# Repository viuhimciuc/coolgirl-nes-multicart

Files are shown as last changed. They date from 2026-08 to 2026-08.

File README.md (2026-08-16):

# 🎮 COOLGIRL - Ultimate Multigame Cartridge for Nintendo Entertainment System

The goal of this project is to create a Nintendo Entertainment System (NES) cartridge in KiCad based on the [coolgirl-famicom-multicart](https://github.com/ClusterM/coolgirl-famicom-multicart) project. This hardware design remains functionally identical to ClusterM's original project and can support up to ~700 games across various mappers.

### 🛠️ Architecture Overview
* **🧠 CPLD Core**: Uses the EPM1270T144 chip to emulate various mappers.
* **💾 Memory Layout**: PRG and CHR data share a single flash memory chip.
* **⚡ Boot Sequence**: The bootloader copies CHR data from Flash to CHR-RAM before game launch.
* **⚙️ Configuration**: Registers manage PRG offsets, bank modes, and mapper IDs.
* **🔒 Security**: Features a dedicated write-protection lock bit to secure settings after configuration.

## 📋 Full Characteristics
* **PRG ROM**: Up to 128 MiB
* **CHR RAM**: Up to 512 KiB
* **PRG RAM**: 32 KiB, non-volatile (FRAM) (optional)

---

## 🚀 How to Build

### 🔌 Hardware

#### 📄 Bill of Materials
* 🛒 [BoM](Coolgirl-NES_Rev6.x/production/bom.csv)

#### 🗺️ Schematic
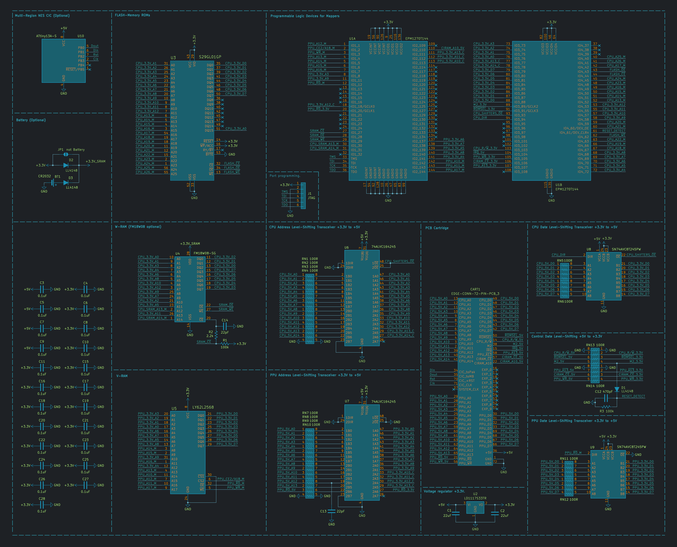
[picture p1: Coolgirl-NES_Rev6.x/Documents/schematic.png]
Schematic

* The [kicad_sch](Coolgirl-NES_Rev6.x/Coolgirl-NES_Rev6.x.kicad_sch) file can be opened using [KiCad](https://kicad.org).
 
#### 🎛️ PCB Design
The board is designed for ordering on [jlcpcb.com](https://jlcpcb.com).

| 🟢 3D Render (Top) | 🔵 3D Render (Bottom) |
| :---: | :---: |
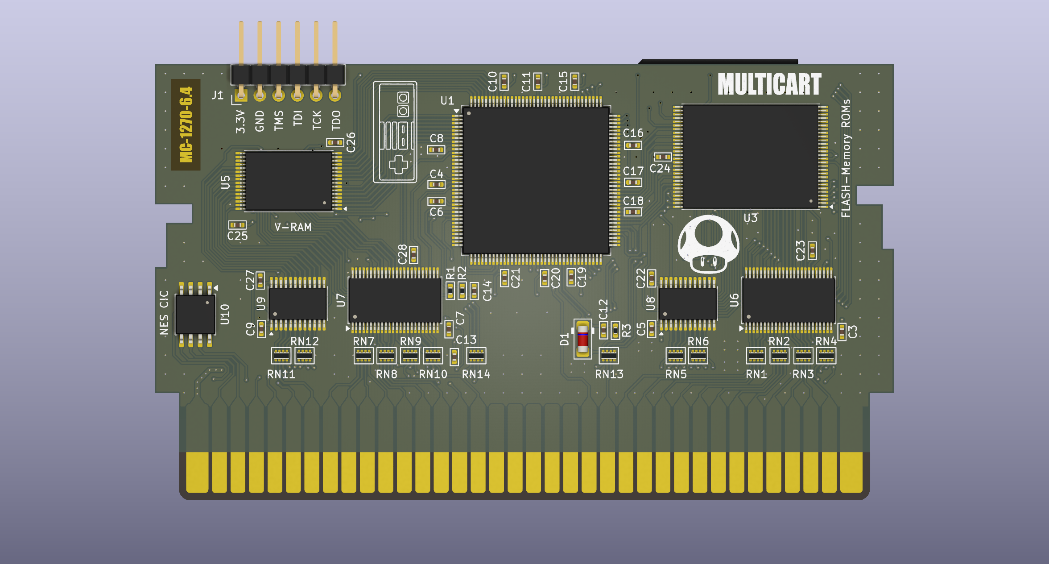
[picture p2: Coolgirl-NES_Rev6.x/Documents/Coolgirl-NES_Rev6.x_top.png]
PCB Top
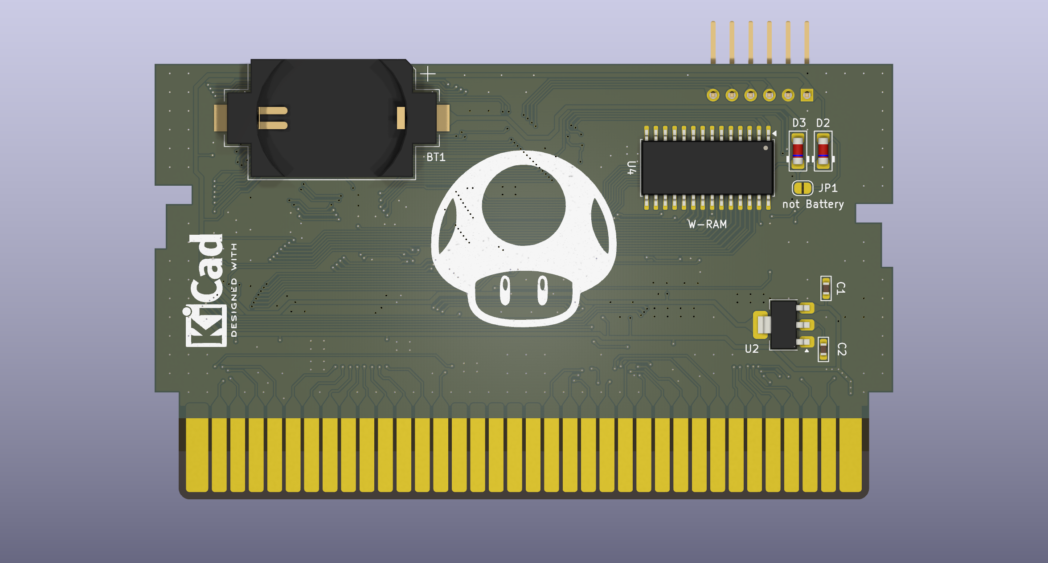
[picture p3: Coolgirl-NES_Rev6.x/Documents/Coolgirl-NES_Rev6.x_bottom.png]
PCB Bottom
|  |  |

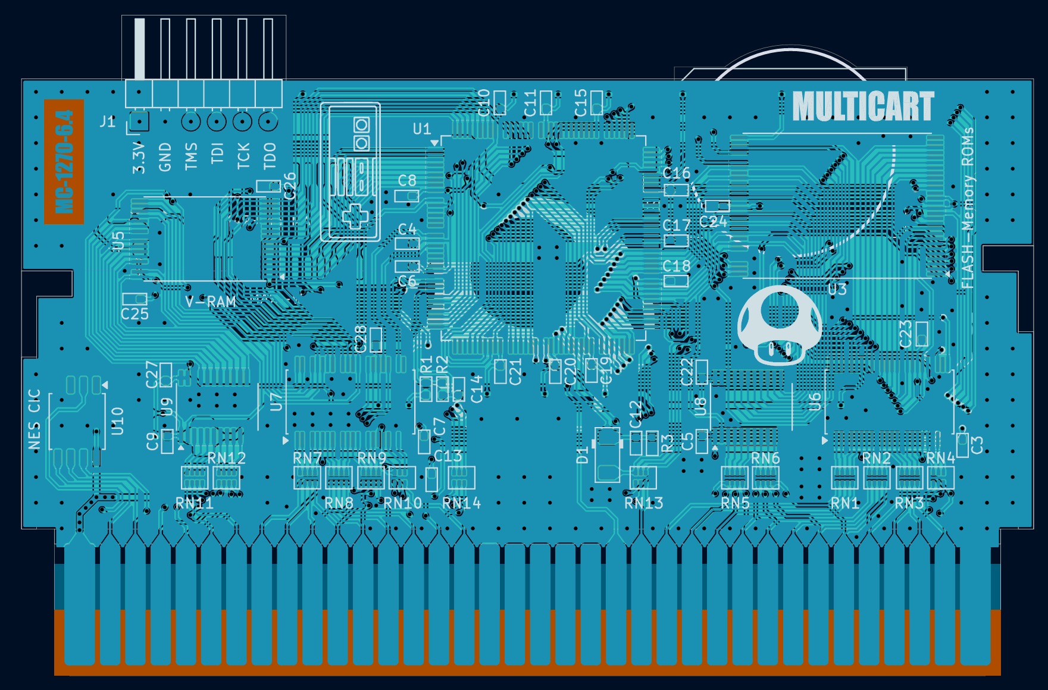
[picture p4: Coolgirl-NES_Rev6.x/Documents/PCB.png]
PCB Layout

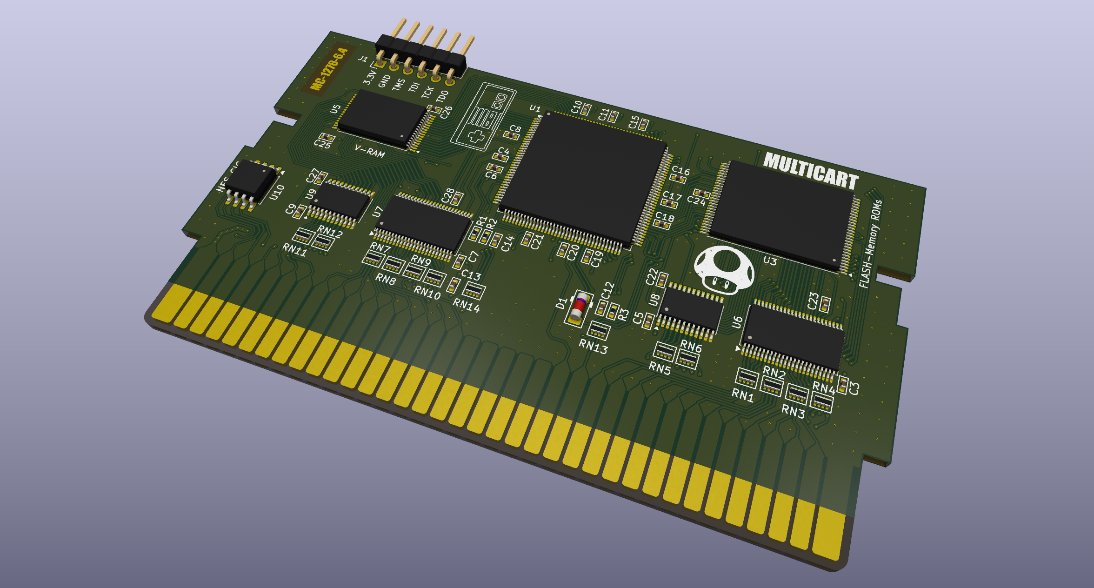
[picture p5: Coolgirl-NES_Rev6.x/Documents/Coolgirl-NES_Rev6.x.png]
Board Preview


* **Layers**: 2
* **PCB Thickness**: 1.2mm
* **Edge Connectors**: Gold fingers are highly recommended

* 📂 Layout source: [kicad_pcb](Coolgirl-NES_Rev6.x/Coolgirl-NES_Rev6.x.kicad_pcb) can be opened using [KiCad](https://kicad.org).
* 📦 Production files: Generated gerbers are located in the [Coolgirl-NES_Rev6.x/production](Coolgirl-NES_Rev6.x/production) directory.

### 💾 Firmware
All firmware and register descriptions are sourced from the [coolgirl-famicom-multicart](https://github.com/ClusterM/coolgirl-famicom-multicart/tree/master) project, corresponding to the board revision.

EPM1270T144 CPLD firmware can be compiled using the [Quartus Prime Lite 21.1](https://www.altera.com/downloads/fpga-development-tools/quartus-prime-lite-edition-design-software-version-21-1-windows). Open [CoolGirl.qpf](https://github.com/ClusterM/coolgirl-famicom-multicart/blob/master/CoolGirl_rev6.x/CoolGirl.qpf) to configure and compile project.

All mappers can't fit into the CPLD at once, so you need to select required mappers in [config file](https://github.com/ClusterM/coolgirl-famicom-multicart/blob/master/CoolGirl_config.vh), so they can fit into 1270 macrocells. Also, you can set `RESET_COMBINATION` parameter to specify software reset button combination, it works on original consoles and some famiclones. Default combination is `8'b11010010` (Left+Start+A+B). Set it to 0 to disable and free some macrocells.

There are JTAG pads on the cartridge board to connect programmer (USB Blaster).

### 💿 ROM Preparing
You can use my [COOLGIRL Multirom Builder based on ca65](https://github.com/viuhimciuc/coolgirl-multirom-builder-ca65)

Loader menu1

and also use from [COOLGIRL Multirom Builder](https://github.com/ClusterM/coolgirl-multirom-builder)

Loader menu2

to combine multiple ROMs into one with menu and loader. ROM can be written to assembled cartridge using [Famicom/NES Dumper/Writer](https://github.com/ClusterM/famicom-dumper-writer). Non-soldered flash memory chip can be written using programmer.

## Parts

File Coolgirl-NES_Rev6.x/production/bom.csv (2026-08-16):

Designator | Footprint | Quantity | Value | LCSC Part #
BT1 | BatteryHolder_Keystone_1060_1x2032 | 1 | CR2032
C1, C2 | 0603 | 2 | 22uF
C10, C11, C15, C16, C17, C18, C19, C20, C21, C22, C23, C24, C25, C26, C27, C28, C3, C4, C5, C6, C7, C8, C9 | 0402 | 23 | 0.1uF
C12 | 0402 | 1 | 470pF
C13, C14 | 0402 | 2 | 22pF
CART1 | PCB_3-CART-72-2.50-CONN | 1 | EDGE-CONN-72-PIN-PCB_3
D1, D2, D3 | D_MiniMELF | 3 | LL4148
J1 | PinHeader_1x06_P2.54mm_Horizontal | 1 | JTAG
R1, R3 | 0402 | 2 | 100k
R2 | 0402 | 1 | 2.2k
RN1, RN10, RN11, RN12, RN13, RN14, RN2, RN3, RN4, RN5, RN6, RN7, RN8, RN9 | R_Array_Concave_4x0402 | 14 | 100R
U1 | LQFP-144_20x20mm_P0.5mm | 1 | EPM1270T144
U10 | SOIC-8_5.3x5.3mm_P1.27mm | 1 | ATtiny13A-S
U2 | SOT-223-3_TabPin2 | 1 | LD1117S33TR
U3 | TSOP-I-56_18.4x14mm_P0.5mm | 1 | S29GL01GP
U4 | SOIC-28W_7.5x17.9mm_P1.27mm | 1 | FM18W08-SG
U5 | TSOP-I-32_11.8x8mm_P0.5mm | 1 | LY62L2568
U6, U7 | TSSOP-48_6.1x12.5mm_P0.5mm | 2 | 74ALVC164245
U8, U9 | TSSOP-24_4.4x7.8mm_P0.65mm | 2 | SN74AVC8T245PW

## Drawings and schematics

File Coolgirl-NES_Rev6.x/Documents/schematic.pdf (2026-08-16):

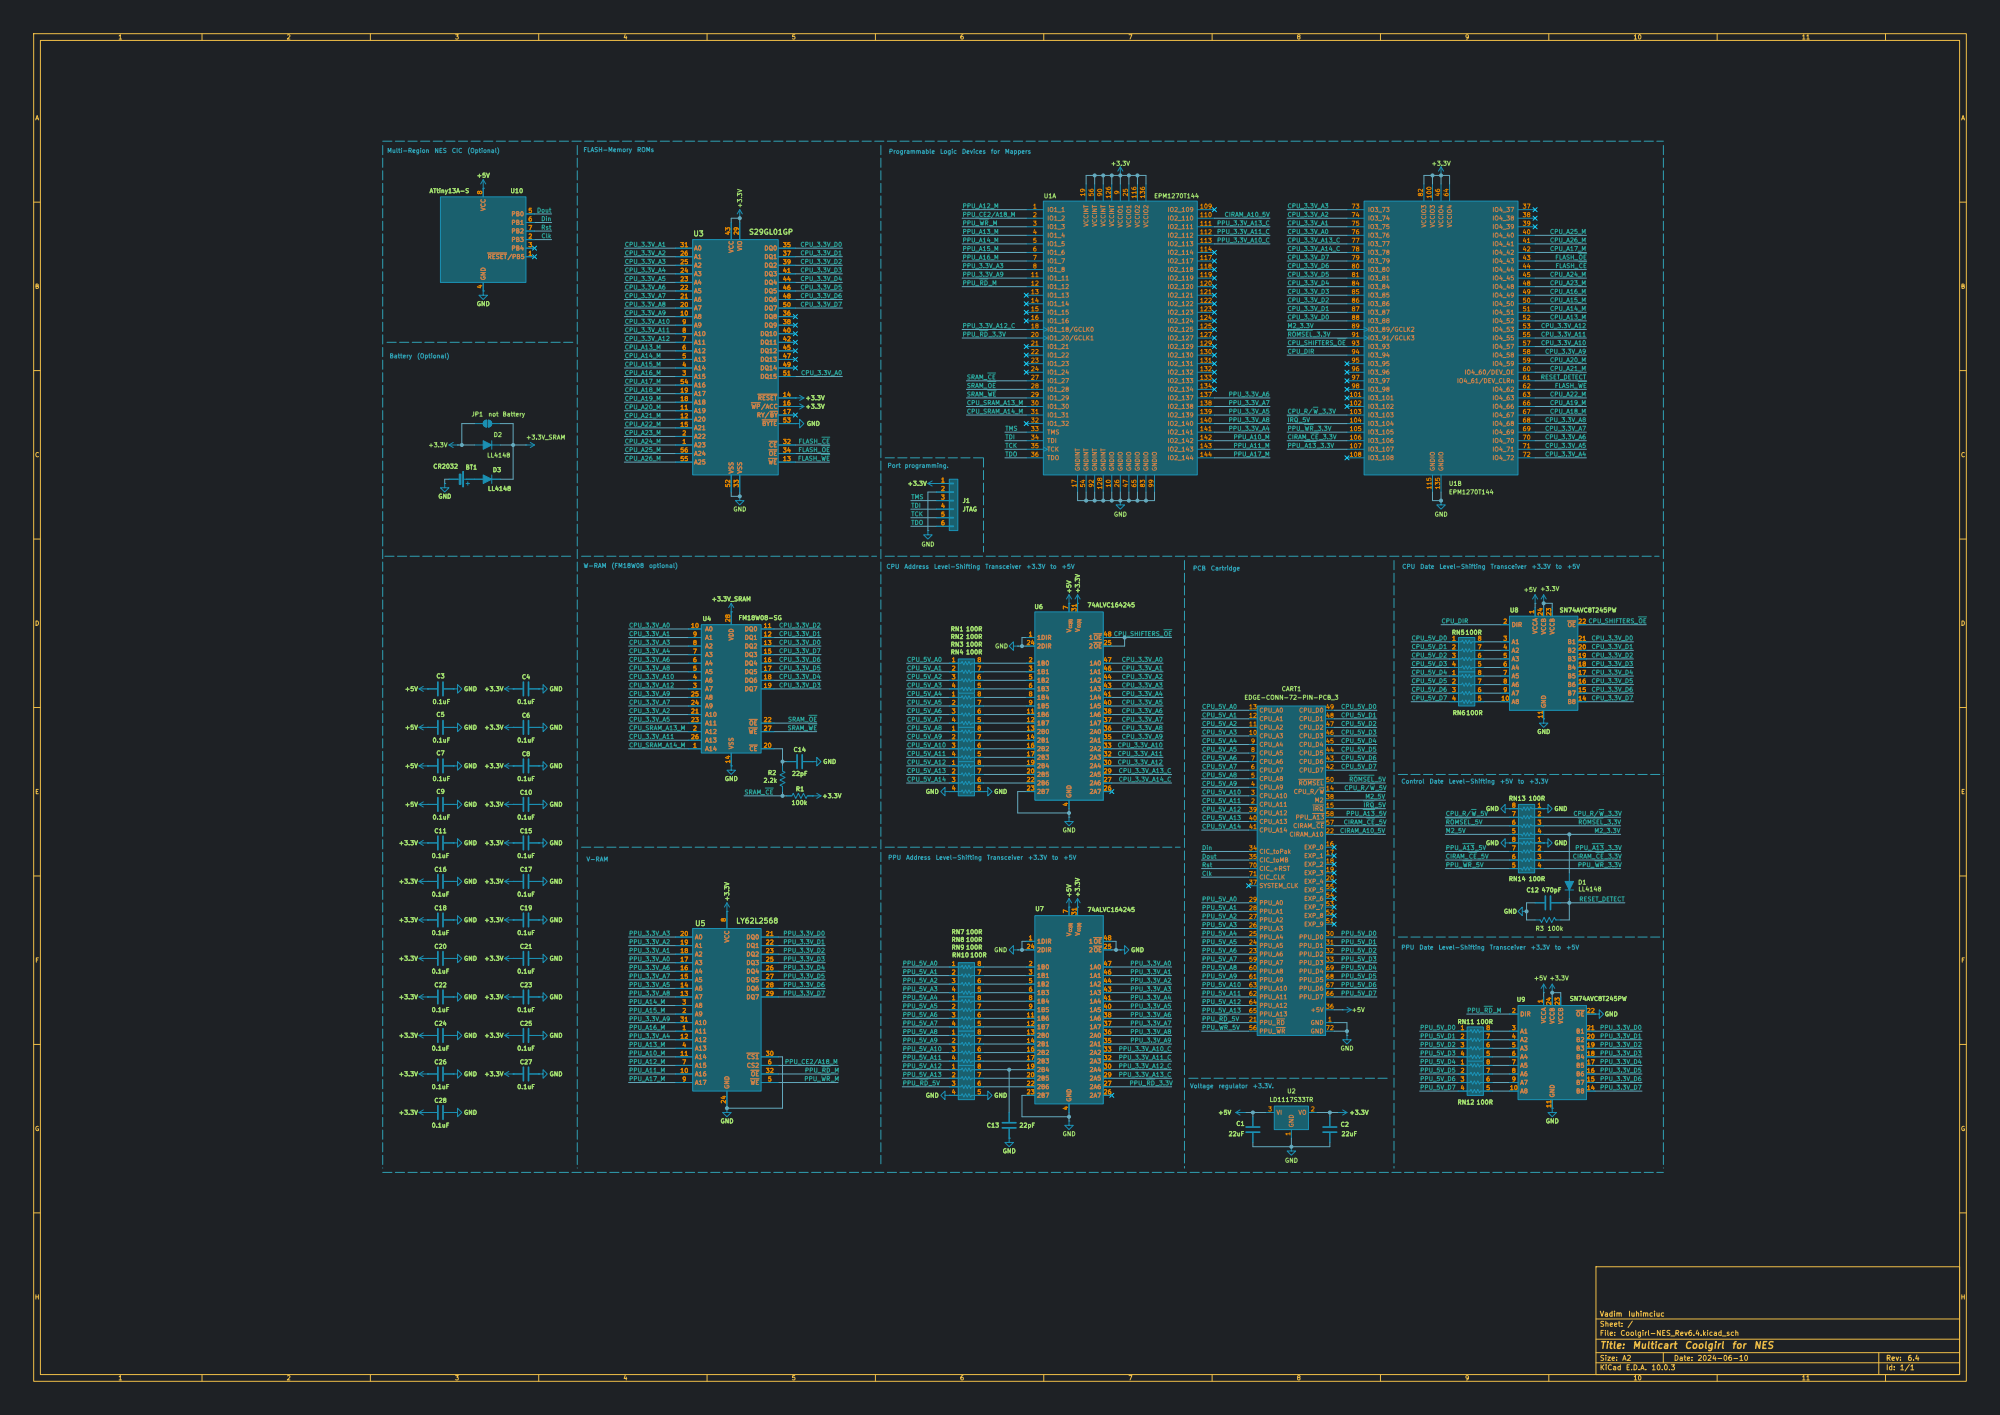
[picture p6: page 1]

Multi-Region NES CIC (Optional)

21 OE 22 VCCB 23 VCCB 24 GND

2B5 20
2B6 22
2B7 23

Sheet: /
File: Coolgirl-NES_Rev6.4.kicad_sch
Title: Multicart Coolgirl for NES

Size: A2 | Rev: 6.4
KiCad E.D.A. 10.0.3 | Id: 1/1

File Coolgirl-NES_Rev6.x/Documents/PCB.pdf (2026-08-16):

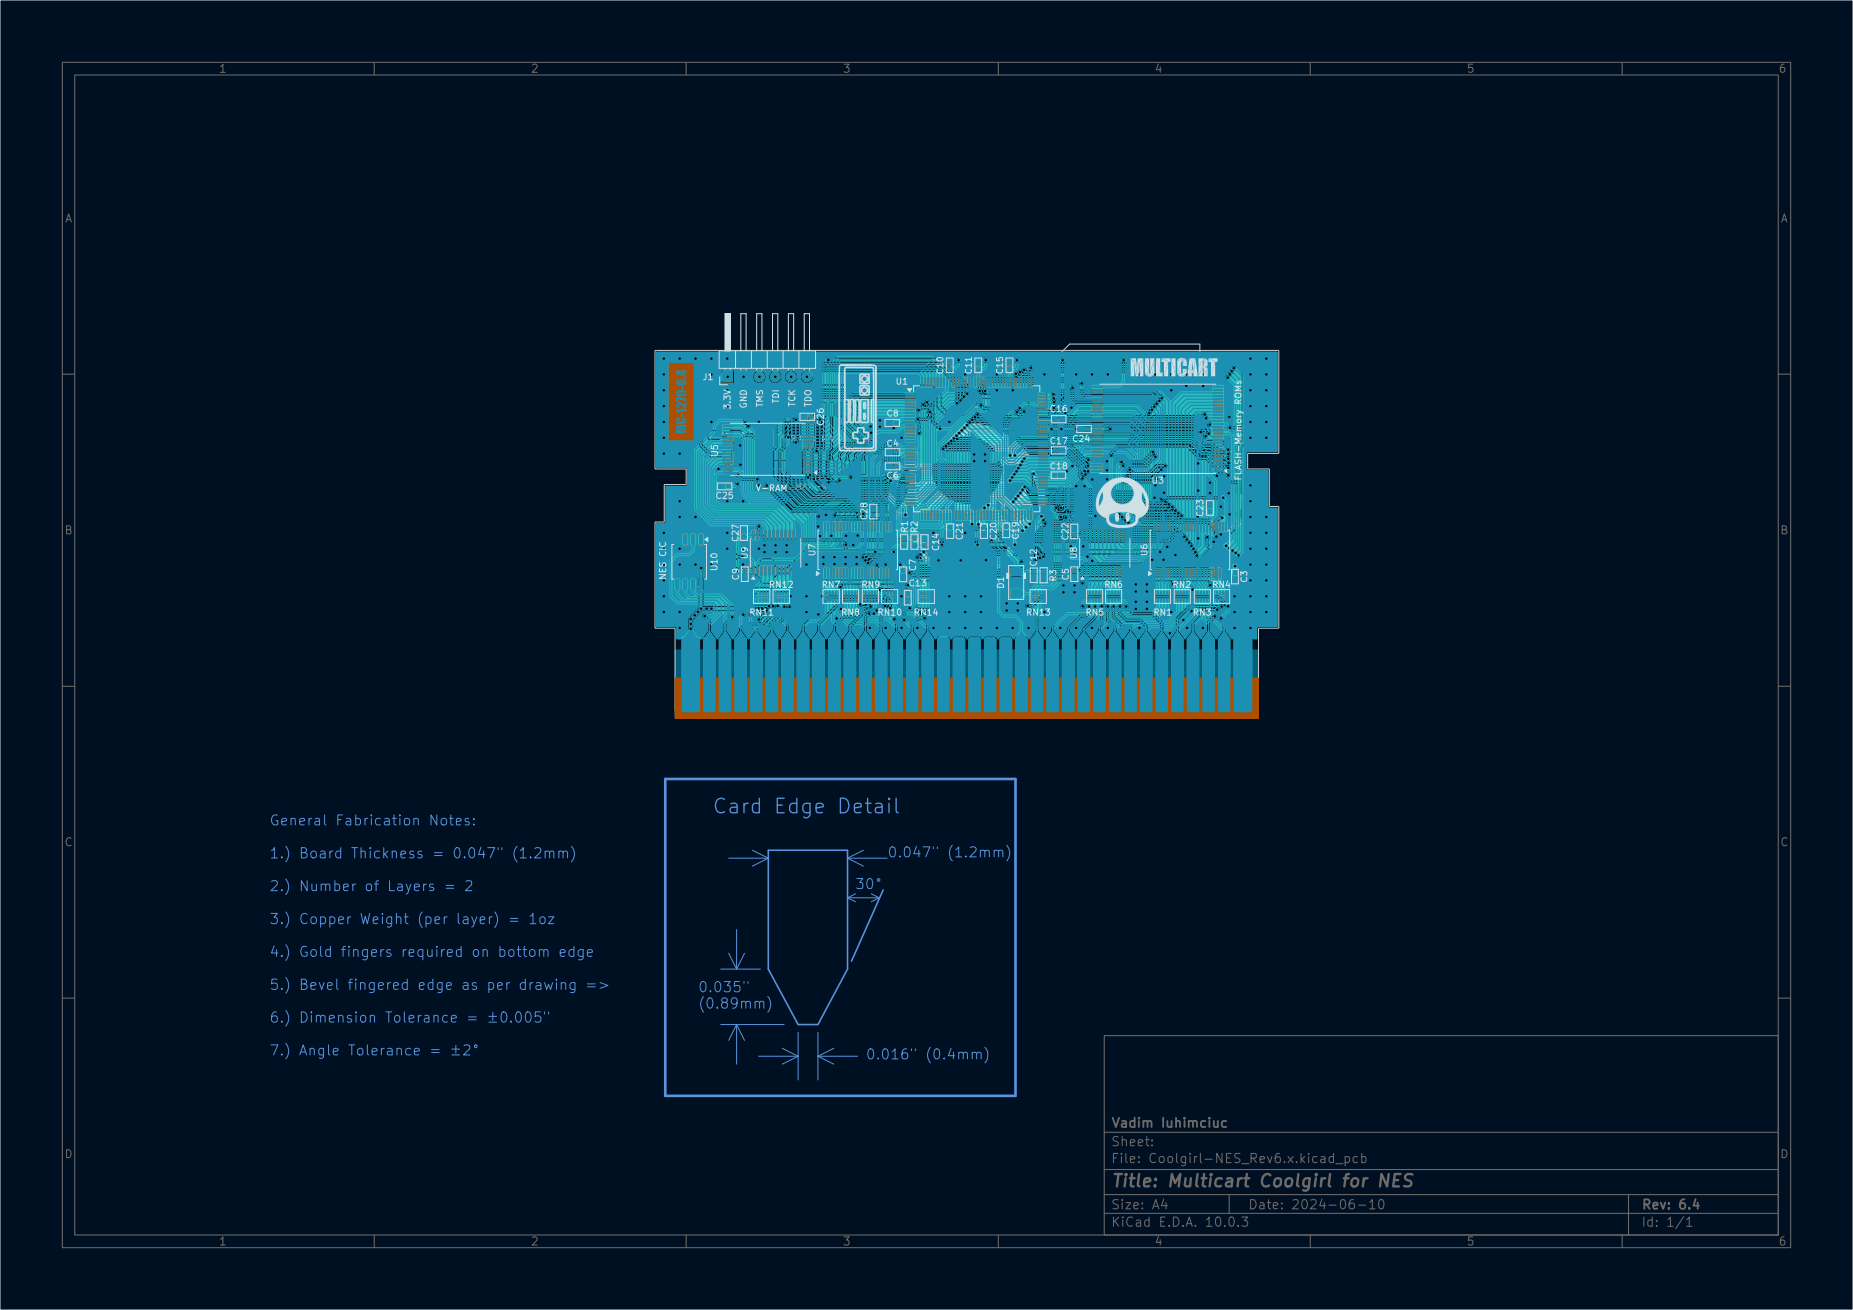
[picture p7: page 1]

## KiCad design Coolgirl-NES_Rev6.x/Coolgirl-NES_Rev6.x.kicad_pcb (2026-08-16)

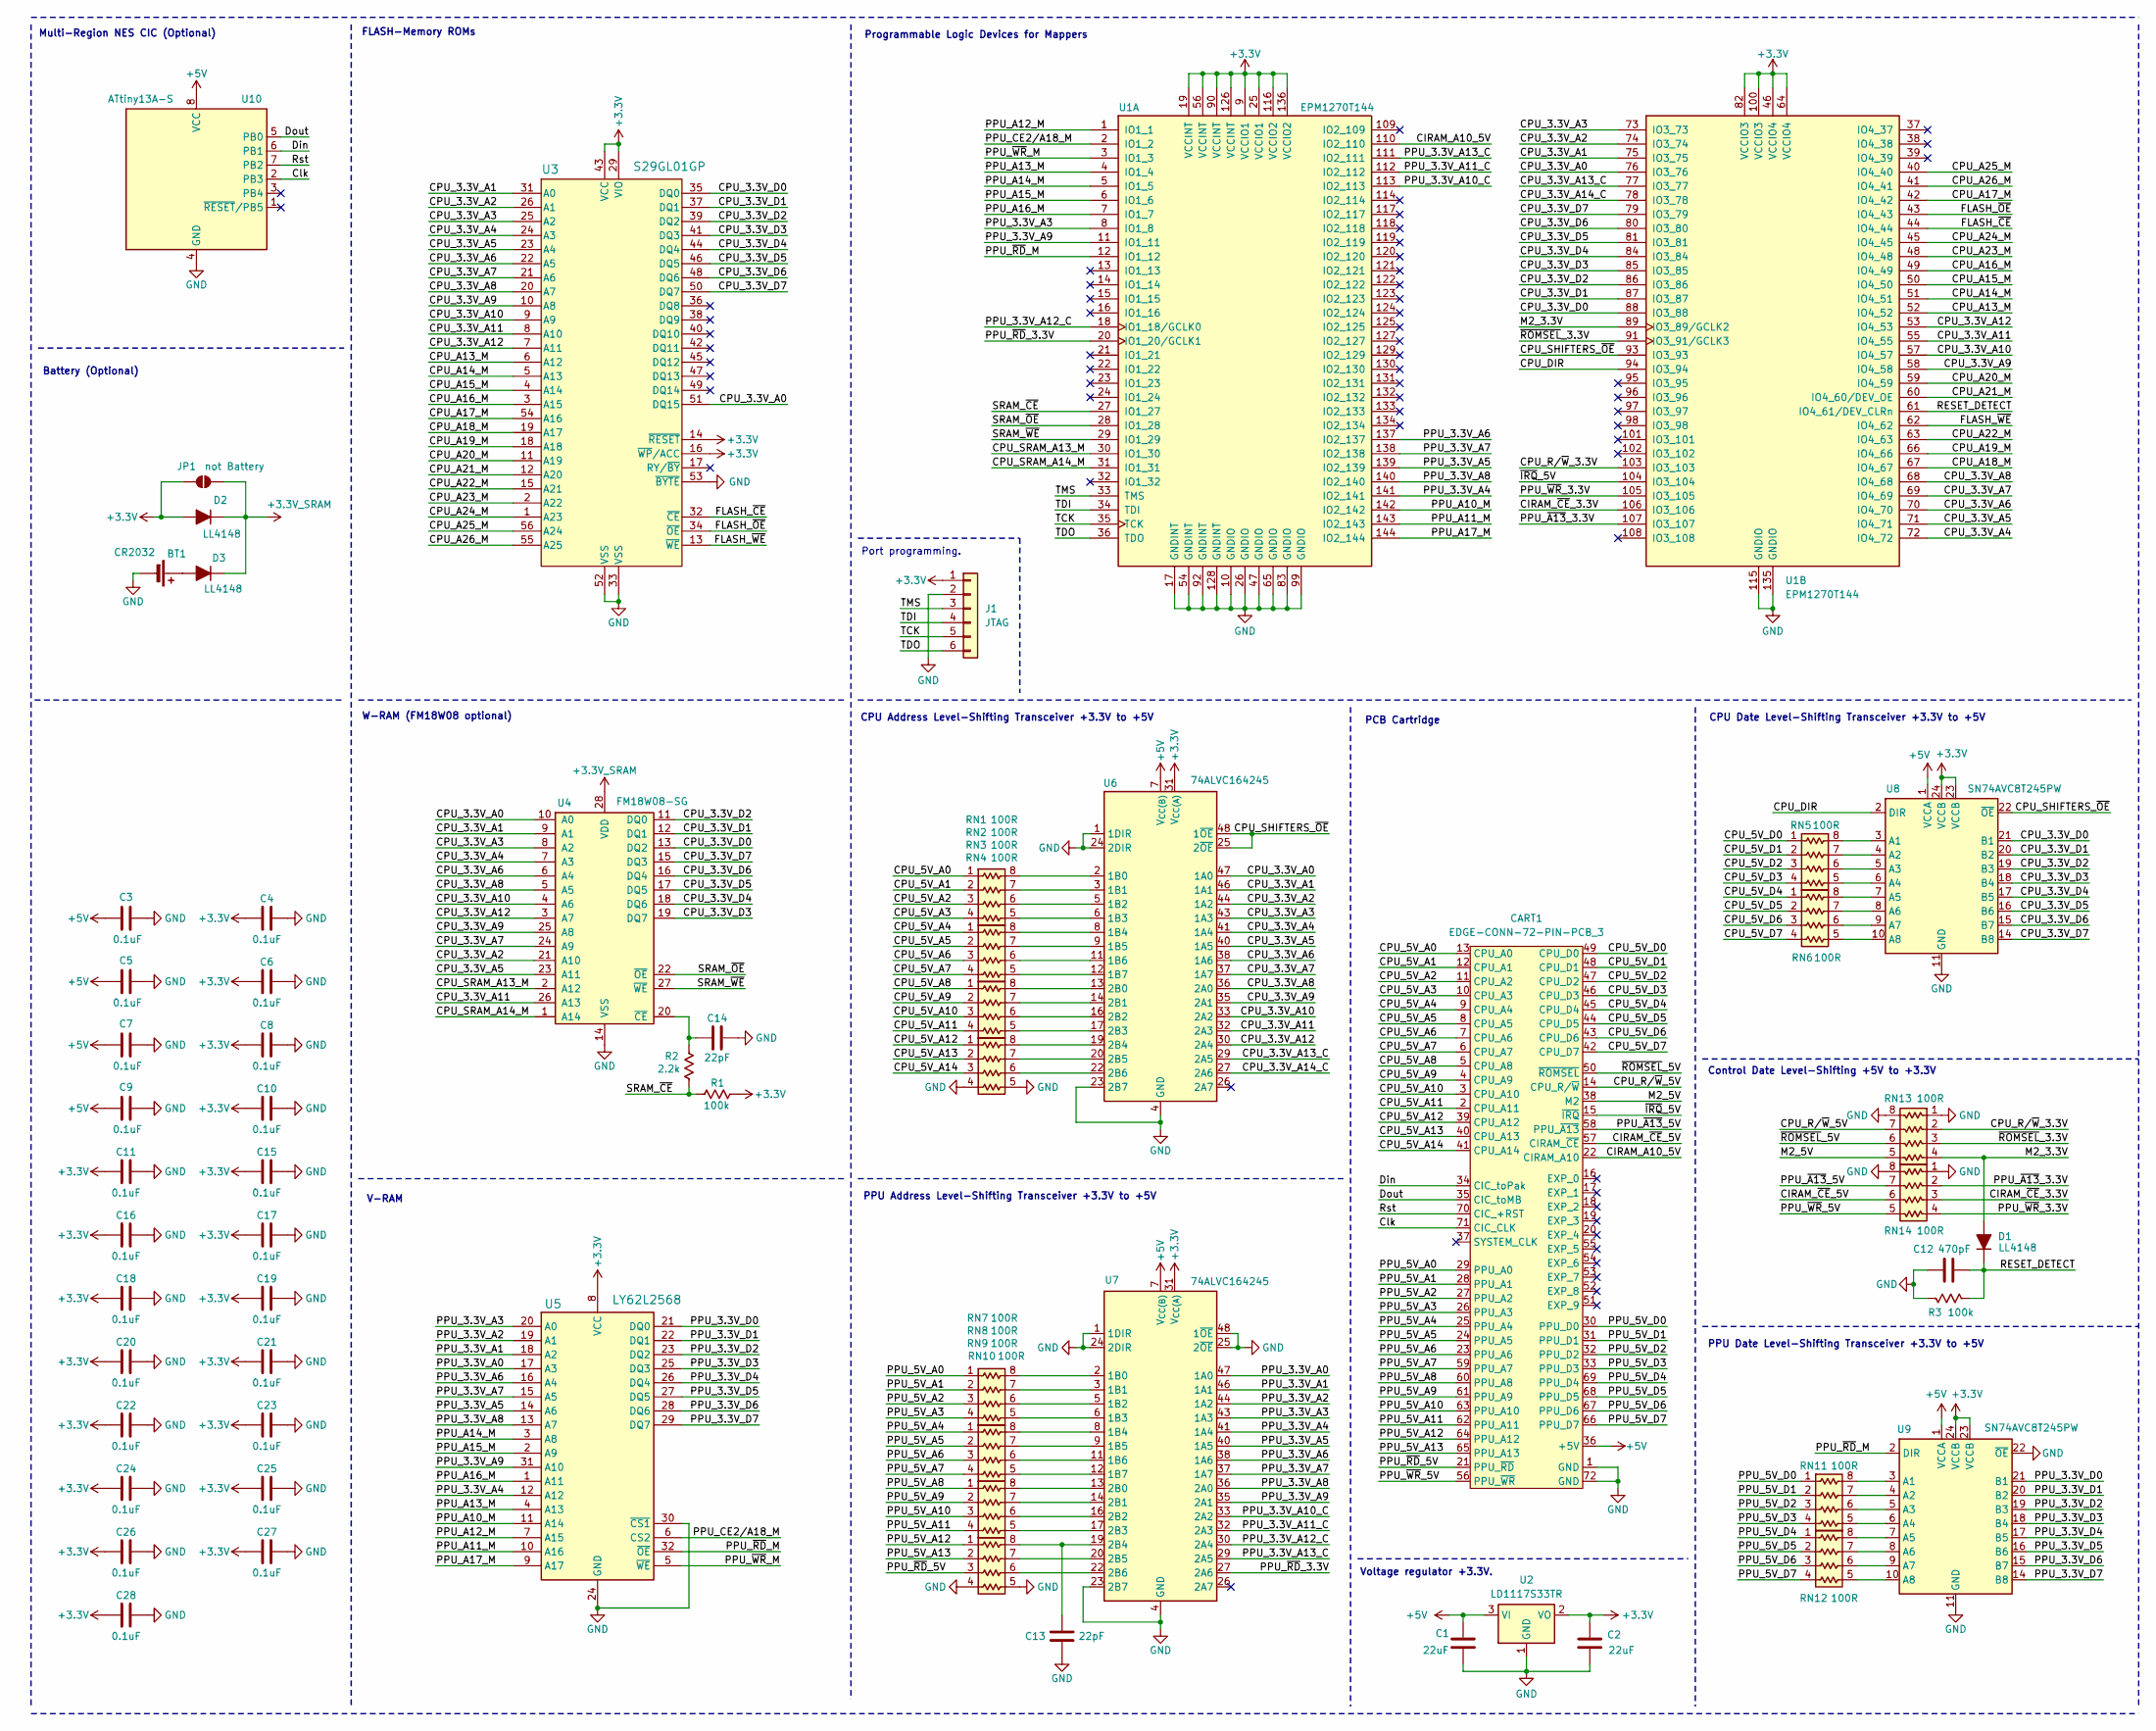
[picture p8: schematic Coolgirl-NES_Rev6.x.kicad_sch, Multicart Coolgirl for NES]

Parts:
BT1: CR2032; BatteryHolder_Keystone_1060_1x2032
C1, C2: 22uF; C_0603_1608Metric_Pad1.08x0.95mm_HandSolder
C3, C4, C5, C6, C7, C8, C9, C10, C11, C15, C16, C17, C18, C19, C20, C21, C22, C23, C24, C25, C26, C27, C28: 0.1uF; C_0402_1005Metric_Pad0.74x0.62mm_HandSolder
C12: 470pF; C_0402_1005Metric_Pad0.74x0.62mm_HandSolder
C13, C14: 22pF; C_0402_1005Metric_Pad0.74x0.62mm_HandSolder
CART1: EDGE-CONN-72-PIN-PCB_3; PCB_3-CART-72-2.50-CONN
D1, D2, D3: LL4148; D_MiniMELF
J1: JTAG; PinHeader_1x06_P2.54mm_Horizontal
JP1: not Battery; SolderJumper-2_P1.3mm_Open_RoundedPad1.0x1.5mm
R1, R3: 100k; R_0402_1005Metric_Pad0.72x0.64mm_HandSolder
R2: 2.2k; R_0402_1005Metric_Pad0.72x0.64mm_HandSolder
RN1, RN2, RN3, RN4, RN5, RN6, RN7, RN8, RN9, RN10, RN11, RN12, RN13, RN14: 100R; R_Array_Concave_4x0402
U1: EPM1270T144; LQFP-144_20x20mm_P0.5mm
U2: LD1117S33TR; SOT-223-3_TabPin2
U3: S29GL01GP; TSOP-I-56_18.4x14mm_P0.5mm
U4: FM18W08-SG; SOIC-28W_7.5x17.9mm_P1.27mm
U5: LY62L2568; TSOP-I-32_11.8x8mm_P0.5mm
U6, U7: 74ALVC164245; TSSOP-48_6.1x12.5mm_P0.5mm
U8, U9: SN74AVC8T245PW; TSSOP-24_4.4x7.8mm_P0.65mm
U10: ATtiny13A-S; SOIC-8_5.3x5.3mm_P1.27mm

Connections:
+3.3V: C2.1, C4.1, C6.1, C8.1, C10.1, C11.1, C15.1, C16.1, C17.1, C18.1, C19.1, C20.1, C21.1, C22.1, C23.1, C24.1, C25.1, C26.1, C27.1, C28.1, D2.2 (A), J1.1, JP1.1 (A), R1.1, U1.9 (VCCIO1), U1.19 (VCCINT), U1.25 (VCCIO1), U1.46 (VCCIO4), U1.56 (VCCINT), U1.64 (VCCIO4), U1.82 (VCCIO3), U1.90 (VCCINT), U1.100 (VCCIO3), U1.116 (VCCIO2), U1.126 (VCCINT), U1.136 (VCCIO2), U2.2 (VO), U3.14 (~RESET), U3.16 (~WP/ACC), U3.29 (VIO), U3.43 (VCC), U5.8 (VCC), U6.31 (V_{CC(A)}), U6.42 (V_{CC(A)}), U7.31 (V_{CC(A)}), U7.42 (V_{CC(A)}), U8.23 (VCCB), U8.24 (VCCB), U9.23 (VCCB), U9.24 (VCCB)
+3.3V_SRAM: D2.1 (K), D3.1 (K), JP1.2 (B), U4.28 (VDD)
+5V: C1.1, C3.1, C5.1, C7.1, C9.1, CART1.36 (+5V), U2.3 (VI), U6.7 (V_{CC(B)}), U6.18 (V_{CC(B)}), U7.7 (V_{CC(B)}), U7.18 (V_{CC(B)}), U8.1 (VCCA), U9.1 (VCCA), U10.8 (VCC)
/CIRAM_A10_5V: CART1.22 (CIRAM_A10), U1.110 (IO2_110)
/CIRAM_~CE_3.3V: RN14.3 (R3.1), U1.106 (IO3_106)
/CIRAM_~CE_5V: CART1.57 (CIRAM_~CE), RN14.6 (R3.2)
/CPU_3.3V_A0: U1.76 (IO3_76), U3.51 (DQ15), U4.10 (A0), U6.47 (1A0)
/CPU_3.3V_A1: U1.75 (IO3_75), U3.31 (A0), U4.9 (A1), U6.46 (1A1)
/CPU_3.3V_A2: U1.74 (IO3_74), U3.26 (A1), U4.21 (A10), U6.44 (1A2)
/CPU_3.3V_A3: U1.73 (IO3_73), U3.25 (A2), U4.8 (A2), U6.43 (1A3)
/CPU_3.3V_A4: U1.72 (IO4_72), U3.24 (A3), U4.7 (A3), U6.41 (1A4)
/CPU_3.3V_A5: U1.71 (IO4_71), U3.23 (A4), U4.23 (A11), U6.40 (1A5)
/CPU_3.3V_A6: U1.70 (IO4_70), U3.22 (A5), U4.6 (A4), U6.38 (1A6)
/CPU_3.3V_A7: U1.69 (IO4_69), U3.21 (A6), U4.24 (A9), U6.37 (1A7)
/CPU_3.3V_A8: U1.68 (IO4_68), U3.20 (A7), U4.5 (A5), U6.36 (2A0)
/CPU_3.3V_A9: U1.58 (IO4_58), U3.10 (A8), U4.25 (A8), U6.35 (2A1)
/CPU_3.3V_A10: U1.57 (IO4_57), U3.9 (A9), U4.4 (A6), U6.33 (2A2)
/CPU_3.3V_A11: U1.55 (IO4_55), U3.8 (A10), U4.26 (A13), U6.32 (2A3)
/CPU_3.3V_A12: U1.53 (IO4_53), U3.7 (A11), U4.3 (A7), U6.30 (2A4)
/CPU_3.3V_A13_C: U1.77 (IO3_77), U6.29 (2A5)
/CPU_3.3V_A14_C: U1.78 (IO3_78), U6.27 (2A6)
/CPU_3.3V_D0: U1.88 (IO3_88), U3.35 (DQ0), U4.13 (DQ2), U8.21 (B1)
/CPU_3.3V_D1: U1.87 (IO3_87), U3.37 (DQ1), U4.12 (DQ1), U8.20 (B2)
/CPU_3.3V_D2: U1.86 (IO3_86), U3.39 (DQ2), U4.11 (DQ0), U8.19 (B3)
/CPU_3.3V_D3: U1.85 (IO3_85), U3.41 (DQ3), U4.19 (DQ7), U8.18 (B4)
/CPU_3.3V_D4: U1.84 (IO3_84), U3.44 (DQ4), U4.18 (DQ6), U8.17 (B5)
/CPU_3.3V_D5: U1.81 (IO3_81), U3.46 (DQ5), U4.17 (DQ5), U8.16 (B6)
/CPU_3.3V_D6: U1.80 (IO3_80), U3.48 (DQ6), U4.16 (DQ4), U8.15 (B7)
/CPU_3.3V_D7: U1.79 (IO3_79), U3.50 (DQ7), U4.15 (DQ3), U8.14 (B8)
/CPU_5V_A0: CART1.13 (CPU_A0), RN1.1 (R1.1)
/CPU_5V_A1: CART1.12 (CPU_A1), RN1.2 (R2.1)
/CPU_5V_A2: CART1.11 (CPU_A2), RN1.3 (R3.1)
/CPU_5V_A3: CART1.10 (CPU_A3), RN1.4 (R4.1)
/CPU_5V_A4: CART1.9 (CPU_A4), RN2.1 (R1.1)
/CPU_5V_A5: CART1.8 (CPU_A5), RN2.2 (R2.1)
/CPU_5V_A6: CART1.7 (CPU_A6), RN2.3 (R3.1)
/CPU_5V_A7: CART1.6 (CPU_A7), RN2.4 (R4.1)
/CPU_5V_A8: CART1.5 (CPU_A8), RN3.1 (R1.1)
/CPU_5V_A9: CART1.4 (CPU_A9), RN3.2 (R2.1)
/CPU_5V_A10: CART1.3 (CPU_A10), RN3.3 (R3.1)
/CPU_5V_A11: CART1.2 (CPU_A11), RN3.4 (R4.1)
/CPU_5V_A12: CART1.39 (CPU_A12), RN4.1 (R1.1)
/CPU_5V_A13: CART1.40 (CPU_A13), RN4.2 (R2.1)
/CPU_5V_A14: CART1.41 (CPU_A14), RN4.3 (R3.1)
/CPU_5V_D0: CART1.49 (CPU_D0), RN5.1 (R1.1)
/CPU_5V_D1: CART1.48 (CPU_D1), RN5.2 (R2.1)
/CPU_5V_D2: CART1.47 (CPU_D2), RN5.3 (R3.1)
/CPU_5V_D3: CART1.46 (CPU_D3), RN5.4 (R4.1)
/CPU_5V_D4: CART1.45 (CPU_D4), RN6.1 (R1.1)
/CPU_5V_D5: CART1.44 (CPU_D5), RN6.2 (R2.1)
/CPU_5V_D6: CART1.43 (CPU_D6), RN6.3 (R3.1)
/CPU_5V_D7: CART1.42 (CPU_D7), RN6.4 (R4.1)
/CPU_A13_M: U1.52 (IO4_52), U3.6 (A12)
/CPU_A14_M: U1.51 (IO4_51), U3.5 (A13)
/CPU_A15_M: U1.50 (IO4_50), U3.4 (A14)
/CPU_A16_M: U1.49 (IO4_49), U3.3 (A15)
/CPU_A17_M: U1.42 (IO4_42), U3.54 (A16)
/CPU_A18_M: U1.67 (IO4_67), U3.19 (A17)
/CPU_A19_M: U1.66 (IO4_66), U3.18 (A18)
/CPU_A20_M: U1.59 (IO4_59), U3.11 (A19)
/CPU_A21_M: U1.60 (IO4_60/DEV_OE), U3.12 (A20)
/CPU_A22_M: U1.63 (IO4_63), U3.15 (A21)
/CPU_A23_M: U1.48 (IO4_48), U3.2 (A22)
/CPU_A24_M: U1.45 (IO4_45), U3.1 (A23)
/CPU_A25_M: U1.40 (IO4_40), U3.56 (A24)
/CPU_A26_M: U1.41 (IO4_41), U3.55 (A25)
/CPU_DIR: U1.94 (IO3_94), U8.2 (DIR)
/CPU_R/~W_3.3V: RN13.2 (R2.1), U1.103 (IO3_103)
/CPU_R/~W_5V: CART1.14 (CPU_R/~W), RN13.7 (R2.2)
/CPU_SHIFTERS_~OE: U1.93 (IO3_93), U6.25 (2~OE), U6.48 (1~OE), U8.22 (~OE)
/CPU_SRAM_A13_M: U1.30 (IO1_30), U4.2 (A12)
/CPU_SRAM_A14_M: U1.31 (IO1_31), U4.1 (A14)
/Clk: CART1.71 (CIC_CLK), U10.2 (PB3)
/Din: CART1.34 (CIC_toPak), U10.6 (PB1)
/Dout: CART1.35 (CIC_toMB), U10.5 (PB0)
/FLASH_~CE: U1.44 (IO4_44), U3.32 (~CE)
/FLASH_~OE: U1.43 (IO4_43), U3.34 (~OE)
/FLASH_~WE: U1.62 (IO4_62), U3.13 (~WE)
/M2_3.3V: D1.2 (A), RN13.4 (R4.1), U1.89 (IO3_89/GCLK2)
/M2_5V: CART1.38 (M2), RN13.5 (R4.2)
/PPU_3.3V_A0: U5.17 (A3), U7.47 (1A0)
/PPU_3.3V_A1: U5.18 (A2), U7.46 (1A1)
/PPU_3.3V_A2: U5.19 (A1), U7.44 (1A2)
/PPU_3.3V_A3: U1.8 (IO1_8), U5.20 (A0), U7.43 (1A3)
/PPU_3.3V_A4: U1.141 (IO2_141), U5.12 (A12), U7.41 (1A4)
/PPU_3.3V_A5: U1.139 (IO2_139), U5.14 (A6), U7.40 (1A5)
/PPU_3.3V_A6: U1.137 (IO2_137), U5.16 (A4), U7.38 (1A6)
/PPU_3.3V_A7: U1.138 (IO2_138), U5.15 (A5), U7.37 (1A7)
/PPU_3.3V_A8: U1.140 (IO2_140), U5.13 (A7), U7.36 (2A0)
/PPU_3.3V_A9: U1.11 (IO1_11), U5.31 (A10), U7.35 (2A1)
/PPU_3.3V_A10_C: U1.113 (IO2_113), U7.33 (2A2)
/PPU_3.3V_A11_C: U1.112 (IO2_112), U7.32 (2A3)
/PPU_3.3V_A12_C: U1.18 (IO1_18/GCLK0), U7.30 (2A4)
/PPU_3.3V_A13_C: U1.111 (IO2_111), U7.29 (2A5)
/PPU_3.3V_D0: U5.21 (DQ0), U9.21 (B1)
/PPU_3.3V_D1: U5.22 (DQ1), U9.20 (B2)
/PPU_3.3V_D2: U5.23 (DQ2), U9.19 (B3)
/PPU_3.3V_D3: U5.25 (DQ3), U9.18 (B4)
/PPU_3.3V_D4: U5.26 (DQ4), U9.17 (B5)
/PPU_3.3V_D5: U5.27 (DQ5), U9.16 (B6)
/PPU_3.3V_D6: U5.28 (DQ6), U9.15 (B7)
/PPU_3.3V_D7: U5.29 (DQ7), U9.14 (B8)
/PPU_5V_A0: CART1.29 (PPU_A0), RN7.1 (R1.1)
/PPU_5V_A1: CART1.28 (PPU_A1), RN7.2 (R2.1)
/PPU_5V_A2: CART1.27 (PPU_A2), RN7.3 (R3.1)
/PPU_5V_A3: CART1.26 (PPU_A3), RN7.4 (R4.1)
/PPU_5V_A4: CART1.25 (PPU_A4), RN8.1 (R1.1)
/PPU_5V_A5: CART1.24 (PPU_A5), RN8.2 (R2.1)
/PPU_5V_A6: CART1.23 (PPU_A6), RN8.3 (R3.1)
/PPU_5V_A7: CART1.59 (PPU_A7), RN8.4 (R4.1)
/PPU_5V_A8: CART1.60 (PPU_A8), RN9.1 (R1.1)
/PPU_5V_A9: CART1.61 (PPU_A9), RN9.2 (R2.1)
/PPU_5V_A10: CART1.63 (PPU_A10), RN9.3 (R3.1)
/PPU_5V_A11: CART1.62 (PPU_A11), RN9.4 (R4.1)
/PPU_5V_A12: CART1.64 (PPU_A12), RN10.1 (R1.1)
/PPU_5V_A13: CART1.65 (PPU_A13), RN10.2 (R2.1)
/PPU_5V_D0: CART1.30 (PPU_D0), RN11.1 (R1.1)
/PPU_5V_D1: CART1.31 (PPU_D1), RN11.2 (R2.1)
/PPU_5V_D2: CART1.32 (PPU_D2), RN11.3 (R3.1)
/PPU_5V_D3: CART1.33 (PPU_D3), RN11.4 (R4.1)
/PPU_5V_D4: CART1.69 (PPU_D4), RN12.1 (R1.1)
/PPU_5V_D5: CART1.68 (PPU_D5), RN12.2 (R2.1)
/PPU_5V_D6: CART1.67 (PPU_D6), RN12.3 (R3.1)
/PPU_5V_D7: CART1.66 (PPU_D7), RN12.4 (R4.1)
/PPU_A10_M: U1.142 (IO2_142), U5.11 (A14)
/PPU_A11_M: U1.143 (IO2_143), U5.10 (A16)
/PPU_A12_M: U1.1 (IO1_1), U5.7 (A15)
/PPU_A13_M: U1.4 (IO1_4), U5.4 (A13)
/PPU_A14_M: U1.5 (IO1_5), U5.3 (A8)
/PPU_A15_M: U1.6 (IO1_6), U5.2 (A9)
/PPU_A16_M: U1.7 (IO1_7), U5.1 (A11)
/PPU_A17_M: U1.144 (IO2_144), U5.9 (A17)
/PPU_CE2/A18_M: U1.2 (IO1_2), U5.6 (CS2)
/PPU_~A13_3.3V: RN14.2 (R2.1), U1.107 (IO3_107)
/PPU_~A13_5V: CART1.58 (PPU_~A13), RN14.7 (R2.2)
/PPU_~RD_3.3V: U1.20 (IO1_20/GCLK1), U7.27 (2A6)
/PPU_~RD_5V: CART1.21 (PPU_~RD), RN10.3 (R3.1)
/PPU_~RD_M: U1.12 (IO1_12), U5.32 (~OE), U9.2 (DIR)
/PPU_~WR_3.3V: RN14.4 (R4.1), U1.105 (IO3_105)
/PPU_~WR_5V: CART1.56 (PPU_~WR), RN14.5 (R4.2)
/PPU_~WR_M: U1.3 (IO1_3), U5.5 (~WE)
/RESET_DETECT: C12.2, D1.1 (K), R3.1, U1.61 (IO4_61/DEV_CLRn)
/Rst: CART1.70 (CIC_+RST), U10.7 (PB2)
/SRAM_~CE: R1.2, R2.1, U1.27 (IO1_27)
/SRAM_~OE: U1.28 (IO1_28), U4.22 (~OE)
/SRAM_~WE: U1.29 (IO1_29), U4.27 (~WE)
/TCK: J1.5, U1.35 (TCK)
/TDI: J1.4, U1.34 (TDI)
/TDO: J1.6, U1.36 (TDO)
/TMS: J1.3, U1.33 (TMS)
/~IRQ_5V: CART1.15 (~IRQ), U1.104 (IO3_104)
/~ROMSEL_3.3V: RN13.3 (R3.1), U1.91 (IO3_91/GCLK3)
/~ROMSEL_5V: CART1.50 (~ROMSEL), RN13.6 (R3.2)
GND: BT1.2 (-), C1.2, C2.2, C3.2, C4.2, C5.2, C6.2, C7.2, C8.2, C9.2, C10.2, C11.2, C12.1, C13.1, C14.2, C15.2, C16.2, C17.2, C18.2, C19.2, C20.2, C21.2, C22.2, C23.2, C24.2, C25.2, C26.2, C27.2, C28.2, CART1.1 (GND), CART1.72 (GND), J1.2, R3.2, RN4.4 (R4.1), RN4.5 (R4.2), RN10.4 (R4.1), RN10.5 (R4.2), RN13.1 (R1.1), RN13.8 (R1.2), RN14.1 (R1.1), RN14.8 (R1.2), U1.10 (GNDIO), U1.17 (GNDINT), U1.26 (GNDIO), U1.47 (GNDIO), U1.54 (GNDINT), U1.65 (GNDIO), U1.83 (GNDIO), U1.92 (GNDINT), U1.99 (GNDIO), U1.115 (GNDIO), U1.128 (GNDINT), U1.135 (GNDIO), U2.1 (GND), U3.33 (VSS), U3.52 (VSS), U3.53 (~BYTE), U4.14 (VSS), U5.24 (GND), U5.30 (~CS1), U6.1 (1DIR), U6.4 (GND), U6.10 (GND), U6.15 (GND), U6.21 (GND), U6.23 (2B7), U6.24 (2DIR), U6.28 (GND), U6.34 (GND), U6.39 (GND), U6.45 (GND), U7.1 (1DIR), U7.4 (GND), U7.10 (GND), U7.15 (GND), U7.21 (GND), U7.23 (2B7), U7.24 (2DIR), U7.25 (2~OE), U7.28 (GND), U7.34 (GND), U7.39 (GND), U7.45 (GND), U7.48 (1~OE), U8.11 (GND), U8.12 (GND), U8.13 (GND), U9.11 (GND), U9.12 (GND), U9.13 (GND), U9.22 (~OE), U10.4 (GND)
unnamed: BT1.1 (+), D3.2 (A)
unnamed: RN1.8 (R1.2), U6.2 (1B0)
unnamed: RN1.7 (R2.2), U6.3 (1B1)
unnamed: RN1.6 (R3.2), U6.5 (1B2)
unnamed: RN1.5 (R4.2), U6.6 (1B3)
unnamed: RN2.8 (R1.2), U6.8 (1B4)
unnamed: RN2.7 (R2.2), U6.9 (1B5)
unnamed: RN2.6 (R3.2), U6.11 (1B6)
unnamed: RN2.5 (R4.2), U6.12 (1B7)
unnamed: RN3.8 (R1.2), U6.13 (2B0)
unnamed: RN3.7 (R2.2), U6.14 (2B1)
unnamed: RN3.6 (R3.2), U6.16 (2B2)
unnamed: RN3.5 (R4.2), U6.17 (2B3)
unnamed: RN4.8 (R1.2), U6.19 (2B4)
unnamed: RN4.7 (R2.2), U6.20 (2B5)
unnamed: RN4.6 (R3.2), U6.22 (2B6)
unnamed: RN5.8 (R1.2), U8.3 (A1)
unnamed: RN5.7 (R2.2), U8.4 (A2)
unnamed: RN5.6 (R3.2), U8.5 (A3)
unnamed: RN5.5 (R4.2), U8.6 (A4)
unnamed: RN6.8 (R1.2), U8.7 (A5)
unnamed: RN6.7 (R2.2), U8.8 (A6)
unnamed: RN6.6 (R3.2), U8.9 (A7)
unnamed: RN6.5 (R4.2), U8.10 (A8)
unnamed: RN7.8 (R1.2), U7.2 (1B0)
unnamed: RN7.7 (R2.2), U7.3 (1B1)
unnamed: RN7.6 (R3.2), U7.5 (1B2)
unnamed: RN7.5 (R4.2), U7.6 (1B3)
unnamed: RN8.8 (R1.2), U7.8 (1B4)
unnamed: RN8.7 (R2.2), U7.9 (1B5)
unnamed: RN8.6 (R3.2), U7.11 (1B6)
unnamed: RN8.5 (R4.2), U7.12 (1B7)
unnamed: RN9.8 (R1.2), U7.13 (2B0)
unnamed: RN9.7 (R2.2), U7.14 (2B1)
unnamed: RN9.6 (R3.2), U7.16 (2B2)
unnamed: RN9.5 (R4.2), U7.17 (2B3)
unnamed: C13.2, RN10.8 (R1.2), U7.19 (2B4)
unnamed: RN10.7 (R2.2), U7.20 (2B5)
unnamed: RN10.6 (R3.2), U7.22 (2B6)
unnamed: RN11.8 (R1.2), U9.3 (A1)
unnamed: RN11.7 (R2.2), U9.4 (A2)
unnamed: RN11.6 (R3.2), U9.5 (A3)
unnamed: RN11.5 (R4.2), U9.6 (A4)
unnamed: RN12.8 (R1.2), U9.7 (A5)
unnamed: RN12.7 (R2.2), U9.8 (A6)
unnamed: RN12.6 (R3.2), U9.9 (A7)
unnamed: RN12.5 (R4.2), U9.10 (A8)
unnamed: C14.1, R2.2, U4.20 (~CE)

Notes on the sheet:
Battery (Optional)
Voltage regulator +3.3V.
PPU Date Level-Shifting Transceiver +3.3V to +5V
Port programming.
Control Date Level-Shifting +5V to +3.3V
CPU Address Level-Shifting Transceiver +3.3V to +5V
FLASH-Memory ROMs
PCB Cartridge
Programmable Logic Devices for Mappers
PPU Address Level-Shifting Transceiver +3.3V to +5V
Multi-Region NES CIC (Optional)
W-RAM (FM18W08 optional)
CPU Date Level-Shifting Transceiver +3.3V to +5V
V-RAM

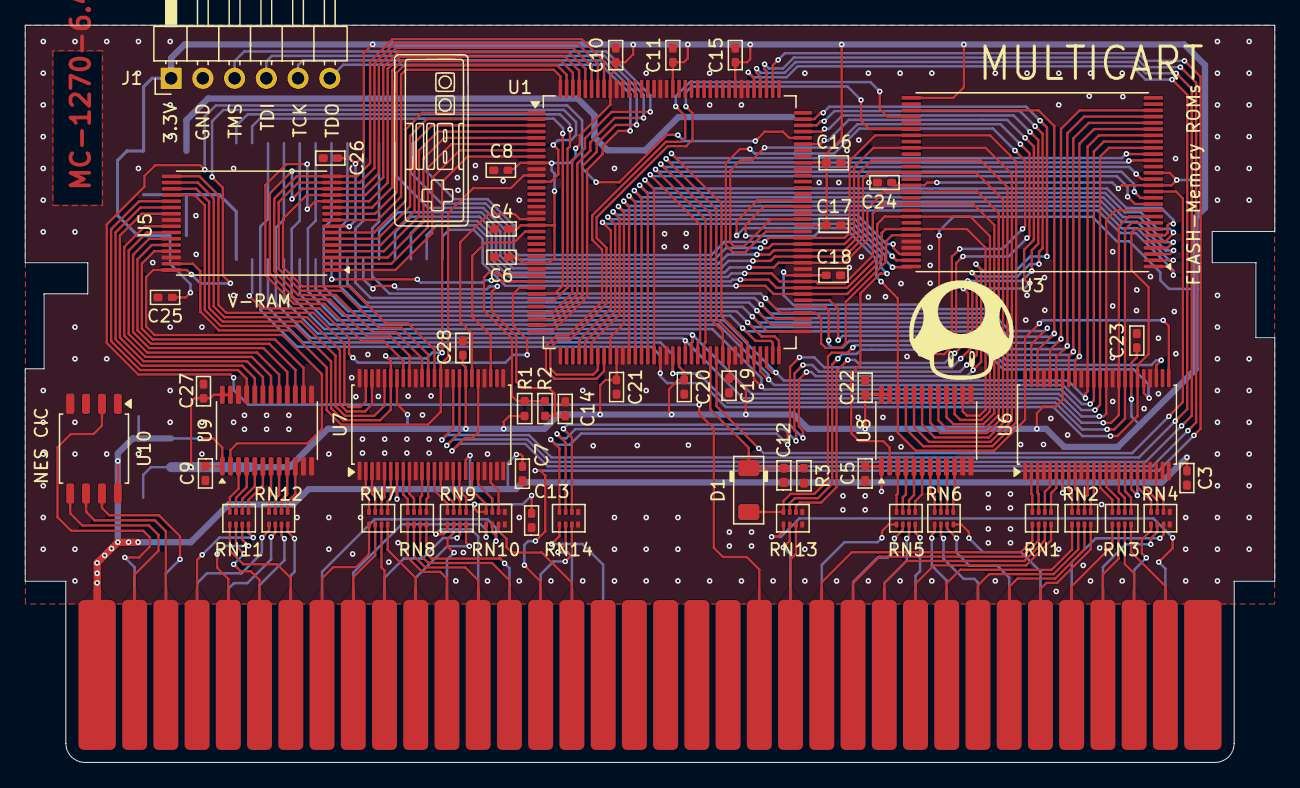
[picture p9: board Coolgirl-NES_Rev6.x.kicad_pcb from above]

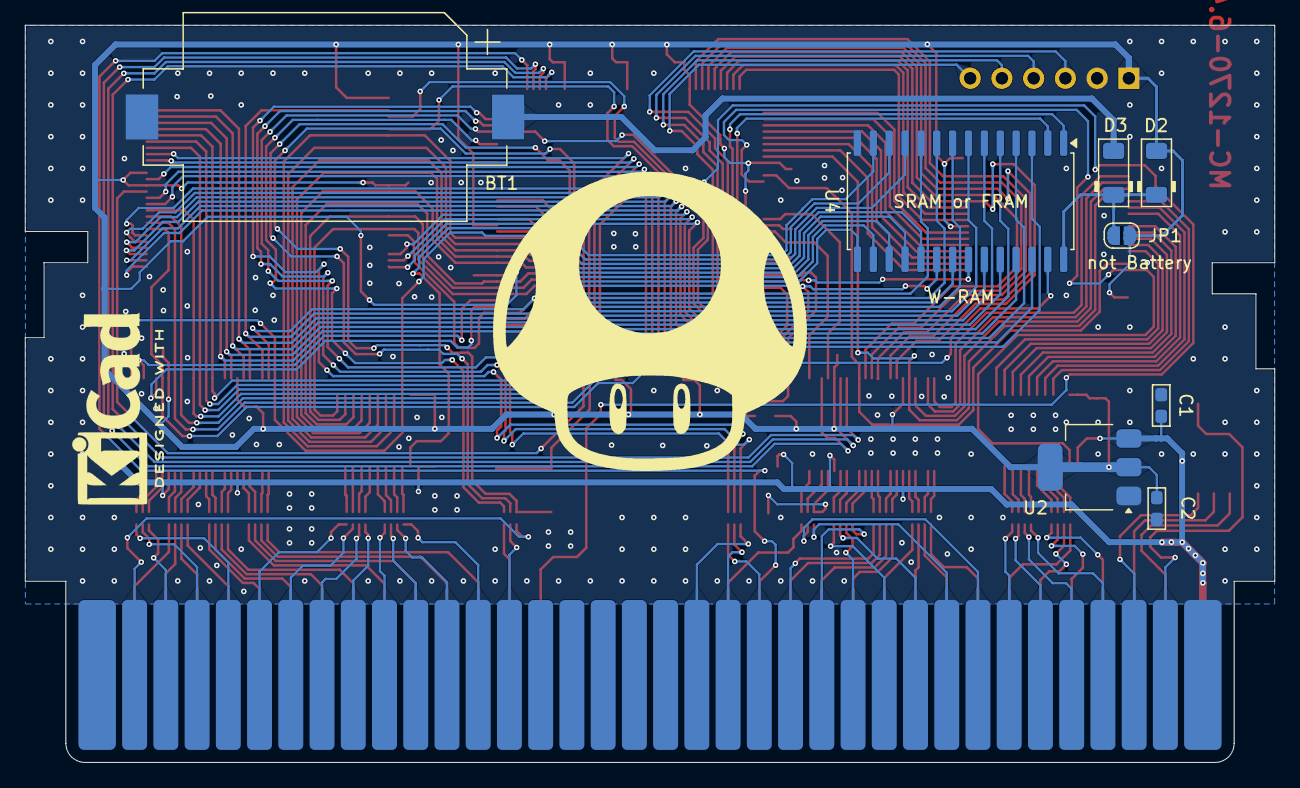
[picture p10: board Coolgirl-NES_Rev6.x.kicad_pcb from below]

Board: 2 copper layers, 100.0 x 59.0 mm, 62 parts (8 on the bottom side), 202 nets.
